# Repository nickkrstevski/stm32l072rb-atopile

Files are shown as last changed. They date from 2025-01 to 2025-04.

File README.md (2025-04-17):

# STM32L072RB
Extreme low power, plenty of peripherals, USB bootloader ready to rip, hell yeah.

## 2025-02-04: V0 Hardware built and powered on->BUG REPORT: Not great, 6☆/10
Got into DFU bootloader after following fixes.
* FIXED: VDD_USB connects straight to USB 5V rail instead of the LDO outputs
* FIXED: VDDA/VSSA straight up not connected
* TODO: Add a blinky are you serious?

## Specs I Care About
Flash:  128kB
EEPROM: 6kB
RAM:    10kB
SPI:    6
I2S:    1
I2C:    3
USART:  4
LPUART: 1
USB:    1 (package will connect to usb C ofc)
GPIO:   51
12bADC: 1 (16channel)
12bDAC: 2
freq:   32 MHz
DCV:    1.8V to 3.6V
PCKG:   LQFP64

## Notes from the getting started guide
https://www.st.com/resource/en/application_note/an4467-getting-started-with-stm32l0xx-hardware-development-stmicroelectronics.pdf

* VDD voltage between 1.8V and 3.6V
* VDD_USB is separate voltage supply for USB XCVR, if not used supply 3.0 to 3.6V
* Need 3V minimum for VDD_USB to have adequate USB line level
* V_core is provided by internal LDO, programmable from 1.2V to 1.8V
* Selectable core voltage ranges which limit clock speed
    * Range 1 = 1.8V | 32Mhz
    * Range 2 = 1.5V | 16Mhz
    * Range 3 = 1.2V | 4.2Mhz
* 10uF ceramic per package + 100nF ceramic for each Vdd pin
* V_dda 1uF ceramic + 100nF ceramic
* Connect Vref1 to V_dda
* Pulldown capacitor recommended on nRST to reduce parasitic reset
* Sysclk can be driven by 4 different sources
    * HSI16 high speed internal oscillator clock
    * HSE high speed external oscillator clock
    * PLL clocl
    * MSI multispeed internal oscillator clock
        * Low cost, no external components
        * 7 Frequencies available from 65.5kHz to 4.2MHz
        * enabled, disabled by RCC_CR register, default on
* Oscillator clocks are divided by 4
* Device has secondary clock sources 37kHz low speed internal RC and 32.768kHz low speed external crystal
* Each clock source can be enabled or disabled independently when not in use
* USB Bootloader is in system memory, BOOT0 = 1 and nBOOT1 = 1
* Connect the SWD port

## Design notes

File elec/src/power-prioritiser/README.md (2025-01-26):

# Power Prioritiser ⚡️

A simple circuit to prioritise a power source over another.

This is useful for situations like a USB-charged battery operated device, where you also want it to work when connected over just USB power.

Often, cheap (and annoyingly expensive) devices neglect this circuit and shutdown when connected over USB. I find this infuriating!

This is better than merely pulling power through the charger circuit because often the inrush currents of a circuit will overwhelm the charger IC and cause it to shut down. This can even lead in the nastiest cases to a boot-loop where the device never charges from a 0% battery.

It's better than a diode because it can handle high-voltage low-priority sources than high and it doesn't have a voltage drop over the low-priority source (typically a battery).

## Limitations

Currently, the components for this circuit are bespokely selected, and aren't parametised for majorly different voltages and currents. It's designed for a USB charged, 1S LiPo powered device.

## Usage

Simple! Hook up `high_priority` and `low_priority` to your power sources, and `out` to your device.

## How it works

When the high-priority power source is connected, the P-FET's gate is pulled high, turning it off. The P-FET thereby stops the low-priority power source from powering the device, even if it's voltage is higher than the high-priority source.

### Both sources connected

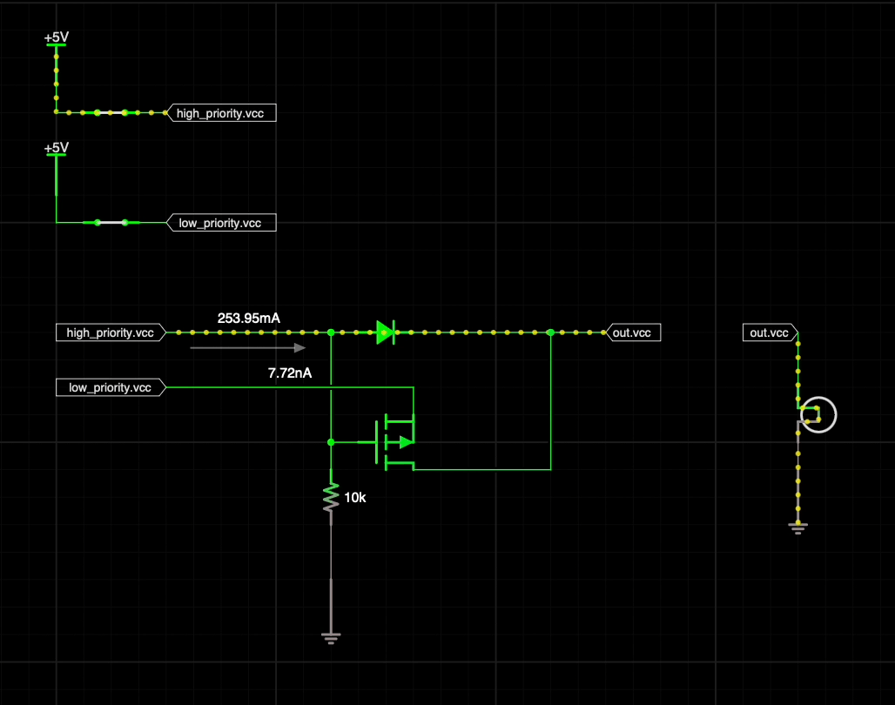
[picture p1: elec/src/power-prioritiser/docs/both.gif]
both


### High-priority source only

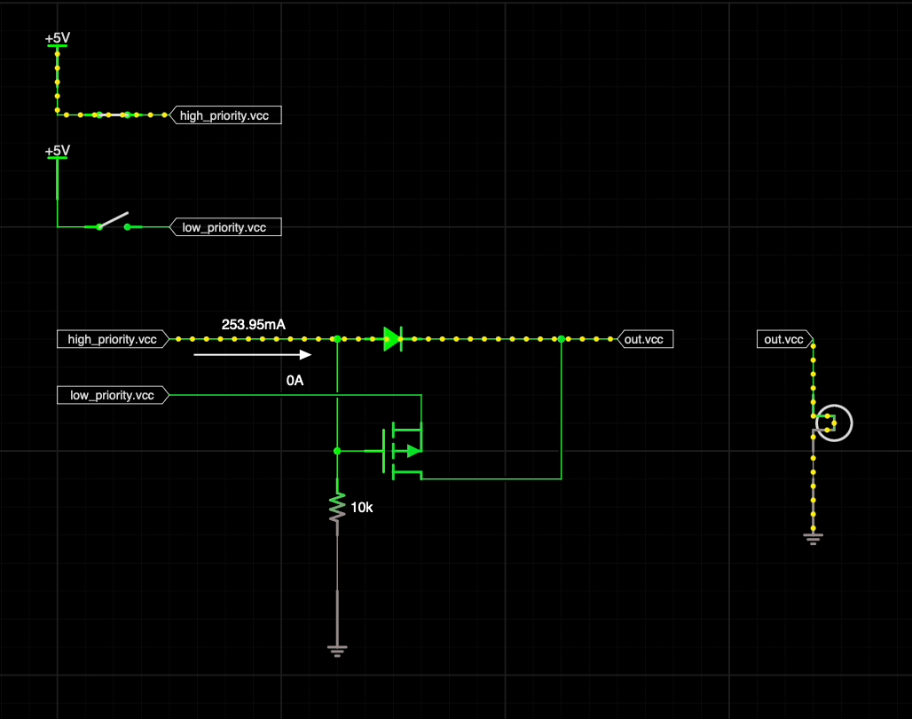
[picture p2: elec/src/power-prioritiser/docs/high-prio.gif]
high


### Low-priority source only

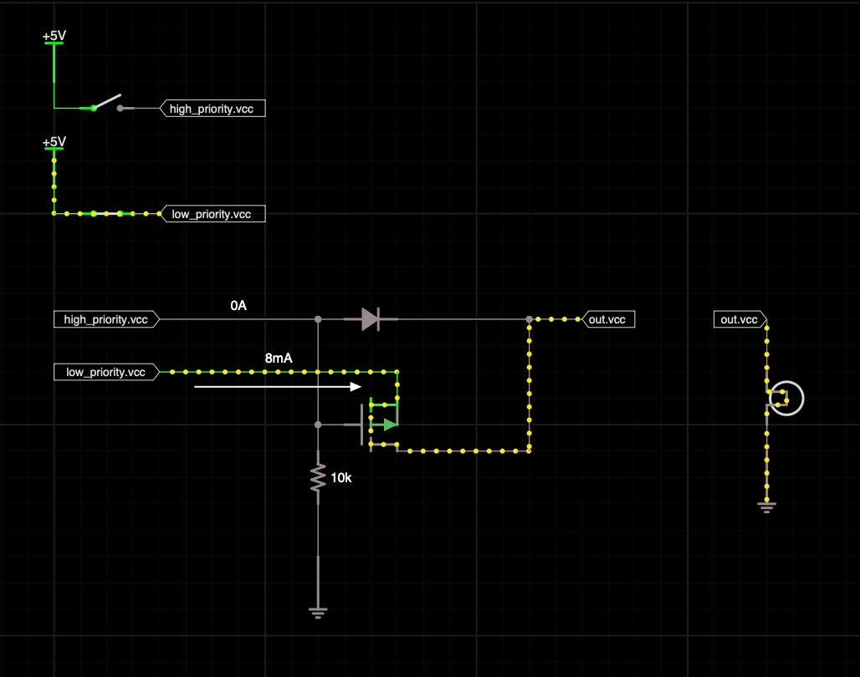
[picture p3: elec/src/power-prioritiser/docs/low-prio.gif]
low


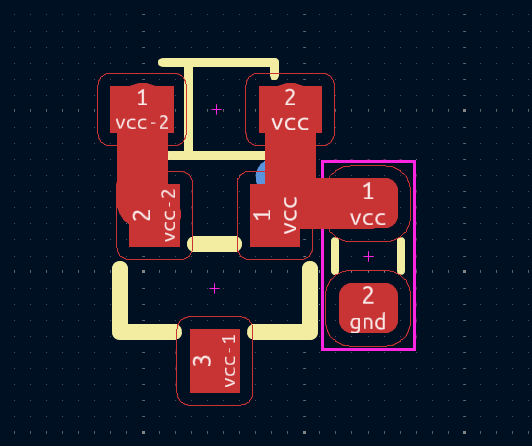
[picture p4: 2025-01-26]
elec/src/power-prioritiser/docs/package.png

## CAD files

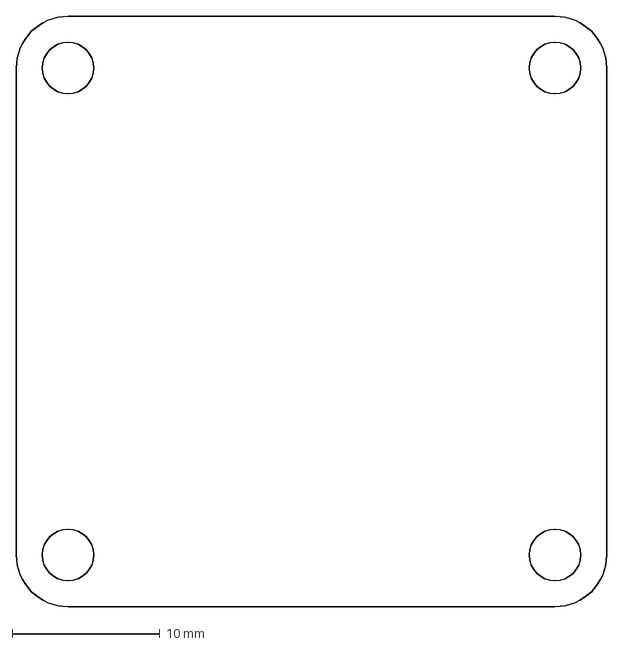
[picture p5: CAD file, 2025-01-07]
elec/src/ams1117-33/mech/template_outline.dxf
40.0 x 40.0 mm

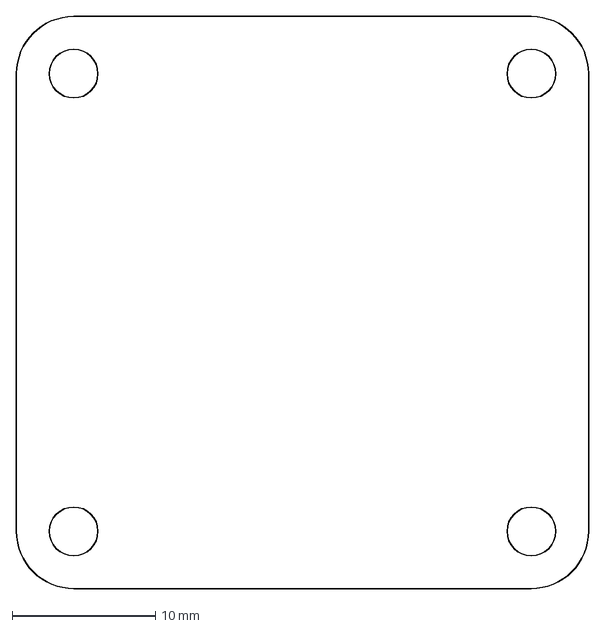
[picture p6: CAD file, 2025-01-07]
elec/src/power-prioritiser/mech/template_40x40.dxf
40.0 x 40.0 mm

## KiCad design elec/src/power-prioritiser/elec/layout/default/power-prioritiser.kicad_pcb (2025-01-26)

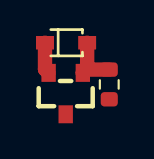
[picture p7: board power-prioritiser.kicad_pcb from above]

Board: 2 copper layers, 3 parts (0 on the bottom side), 2 nets.

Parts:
DS1: ?; SOD-323_L1.8-W1.3-LS2.5-RD
Q1: ?; SOT-23_L2.9-W1.3-P1.90-LS2.4-BR
R1: 100mW Thick Film Resistors 75V ±100ppm/℃ ±1% 10kΩ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; R0603

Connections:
vcc: DS1.2, Q1.1, R1.1
vcc-2: DS1.1, Q1.2

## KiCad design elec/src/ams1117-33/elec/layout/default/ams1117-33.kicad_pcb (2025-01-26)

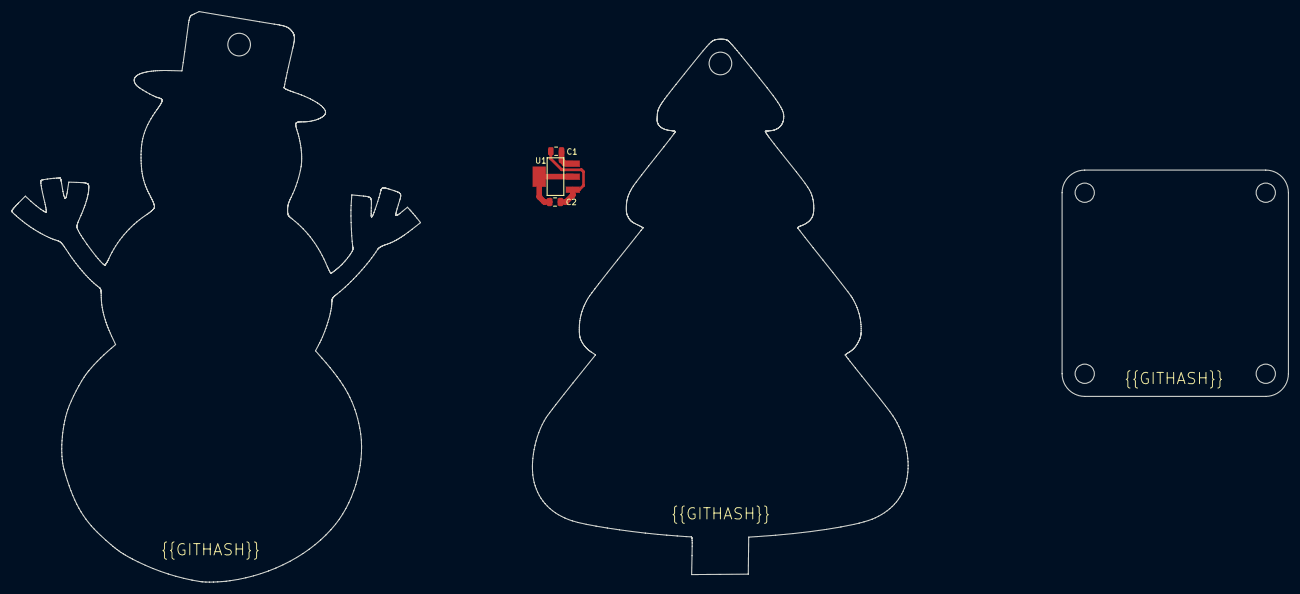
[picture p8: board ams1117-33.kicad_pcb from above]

Board: 2 copper layers, 66.4 x 94.6 mm, 3 parts (0 on the bottom side), 3 nets.

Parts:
C1, C2: 25V 10uF X5R ±10% 0805 Multilayer Ceramic Capacit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; C0805
U1: SOT-223-3_L6.5-W3.4-P2.30-LS7.0-BR

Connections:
gnd: C1.2, C2.2, U1.1
vcc: C1.1, U1.3
vcc-1: C2.1, U1.2, U1.4

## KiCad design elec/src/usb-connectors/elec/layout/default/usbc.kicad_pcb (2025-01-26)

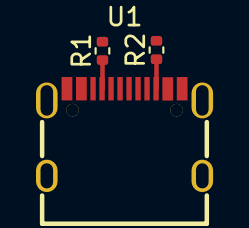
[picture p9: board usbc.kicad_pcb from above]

Board: 2 copper layers, 3 parts (0 on the bottom side), 6 nets.

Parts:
R1, R2: Chip Resistor - Surface Mount 4.7KOhms ±5% 1/16W 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; R0402
U1: USB-C-SMD_KH-TYPE-C-16P

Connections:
cc1: R1.1, U1.A5
cc2: R2.1, U1.B5
dm: U1.A7, U1.B7
dp: U1.A6, U1.B6
gnd: R1.2, R2.2, U1.1, U1.2, U1.3, U1.4, U1.A1, U1.A12, U1.B1, U1.B12
vcc: U1.A4, U1.A9, U1.B4, U1.B9

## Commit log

2025-01-07 added stm32l072rbt6 component
2025-01-26 added usb peripheral and outlined i2c and spi
    [usbc.kicad_pcb, usbc.kicad_sch]
2025-01-26 added proper power managment
    [ams1117-33.kicad_pcb, ams1117-33.kicad_sch, power-prioritiser.kicad_pcb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]
